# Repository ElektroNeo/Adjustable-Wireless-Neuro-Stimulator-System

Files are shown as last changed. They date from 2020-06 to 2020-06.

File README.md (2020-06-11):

# Adjustable Wireless Neuro Stimulator System
This project is made for the Design Project lecture. With this system, you can control output current by using Android application which made with [App Inventor](http://ai2.appinventor.mit.edu/).
### Notes
- The maximum output current is 5.5mA.
- The maximum Pulse High, Pulse Low, and Working Time values on the application are 255.
- Current source and system power supplies must not share the same ground.

## Used Microcontroller Features
In the software used PIC16F1713 microcontroller features listed below.
- DAC
- EUSART
- Timer0
- Interrupt

## Components
- 1x PIC16F1713 Microcontroller
- 1x HC-06 Bluethoot Module
- 2x LMC6482IN Amplifier
- 1x L7805 5V Regulator
- 3x Screw Terminal
- +12V DC Power Supply (for the current source)
- +7V - +12V DC Power Supply or Battery (for the system)
- 2x 120 Ohm Resistor
- 2x 560 Ohm Resistor
- 3x 1k Ohm Resistor
- 2x 330 Ohm Resistor
- 2x 10uF Capacitor
- 2x Red LED
- 1x Green LED
- Others (Button, pin header, switch)

## App
| Disconnected App  | Connected App |
| :---: | :---: |
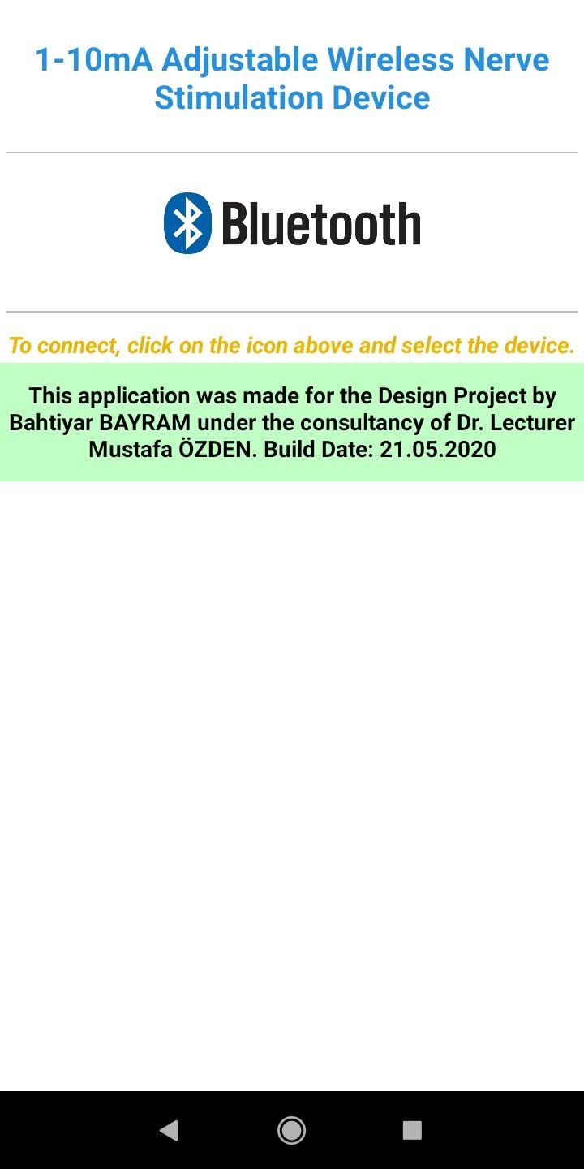
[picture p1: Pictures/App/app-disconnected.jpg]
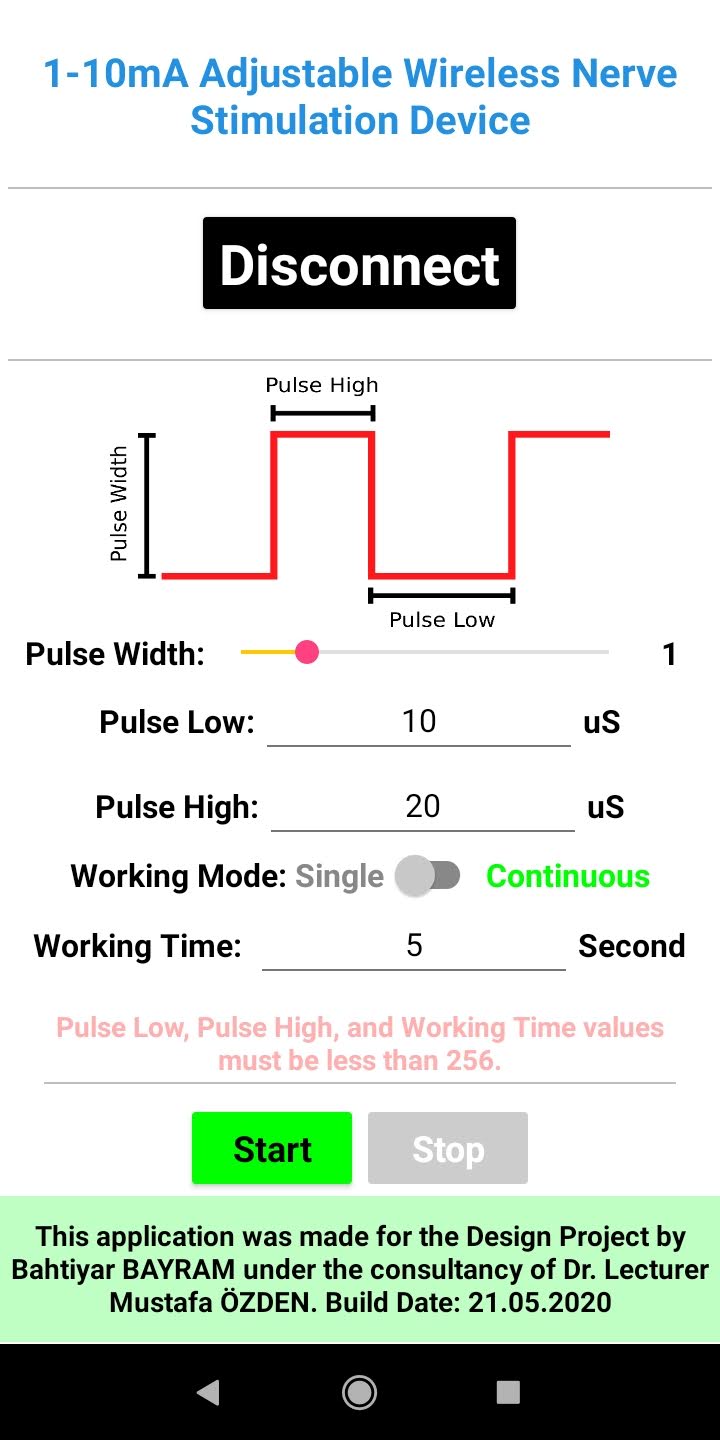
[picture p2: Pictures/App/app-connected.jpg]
|   |   |

## Schematic
| |  |
| :---: | :---: |
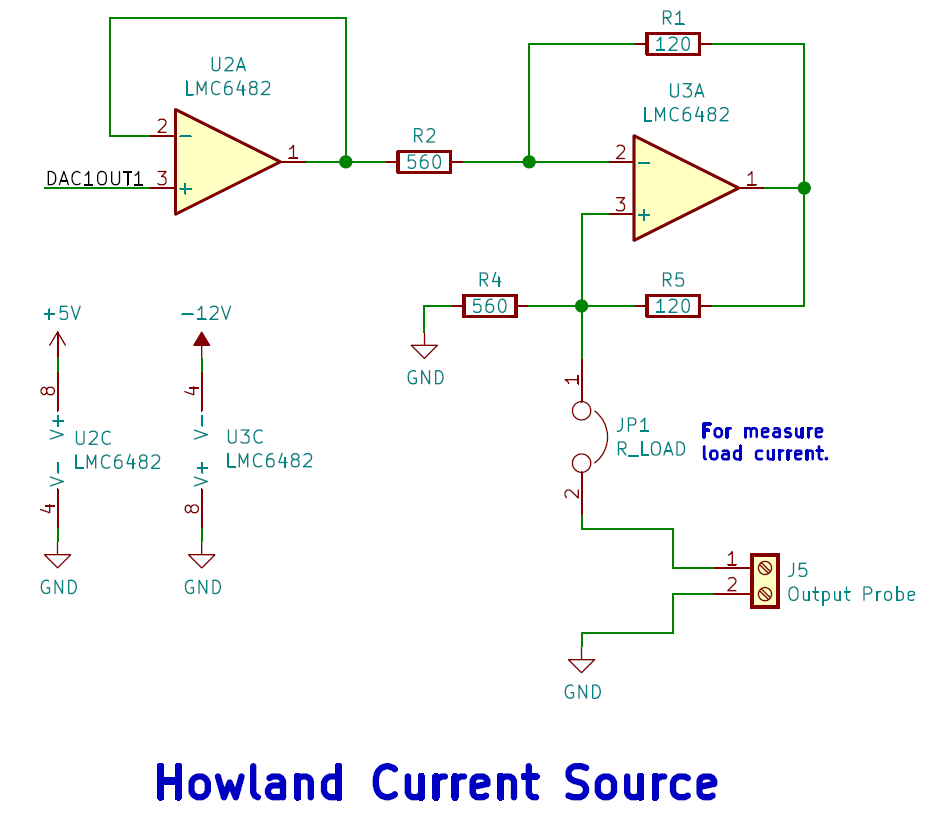
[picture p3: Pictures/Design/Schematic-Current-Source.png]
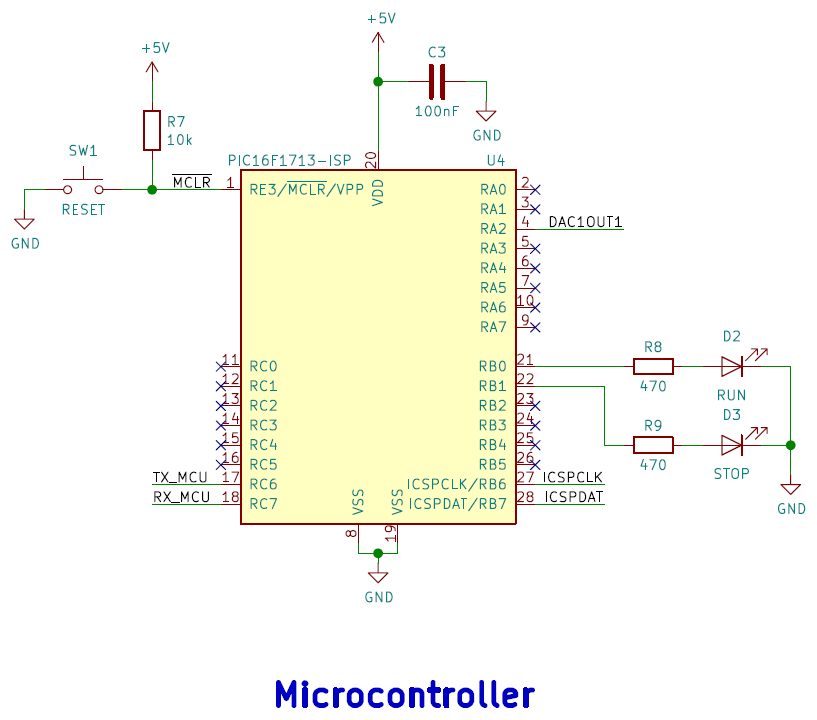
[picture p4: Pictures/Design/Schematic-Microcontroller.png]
|   |   |
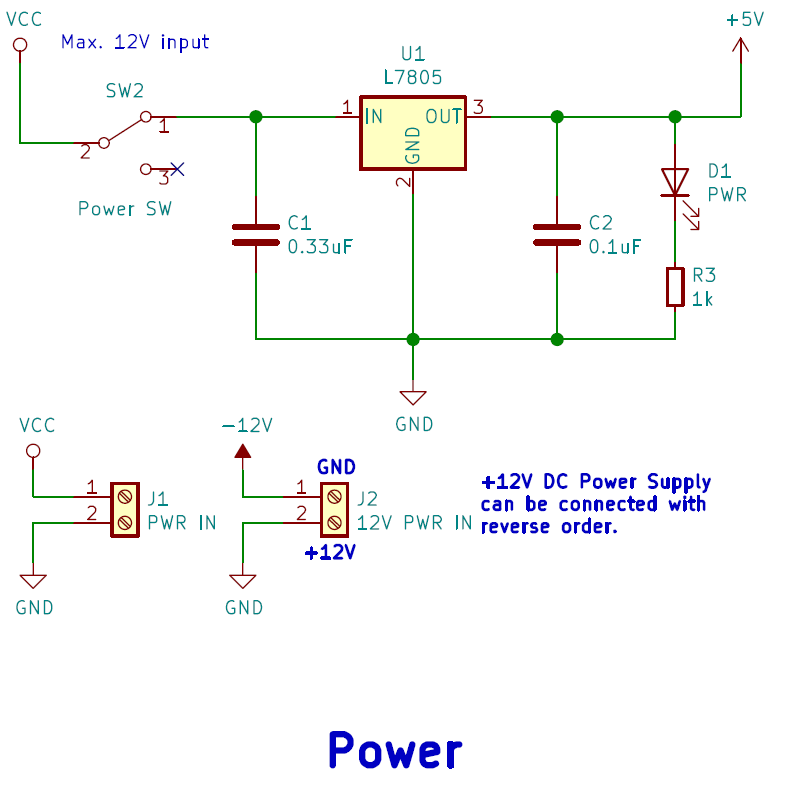
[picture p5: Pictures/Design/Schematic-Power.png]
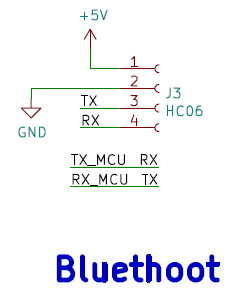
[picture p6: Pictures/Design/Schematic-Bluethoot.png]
|   |   |
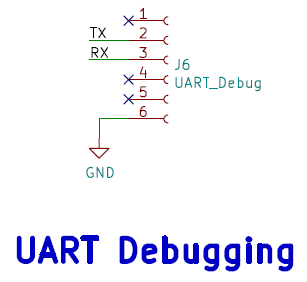
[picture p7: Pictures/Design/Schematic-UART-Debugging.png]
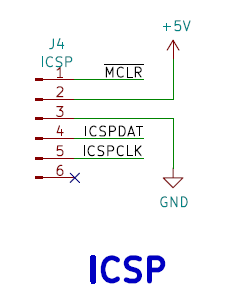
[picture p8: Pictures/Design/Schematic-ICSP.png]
|   |   |

## 3D Design
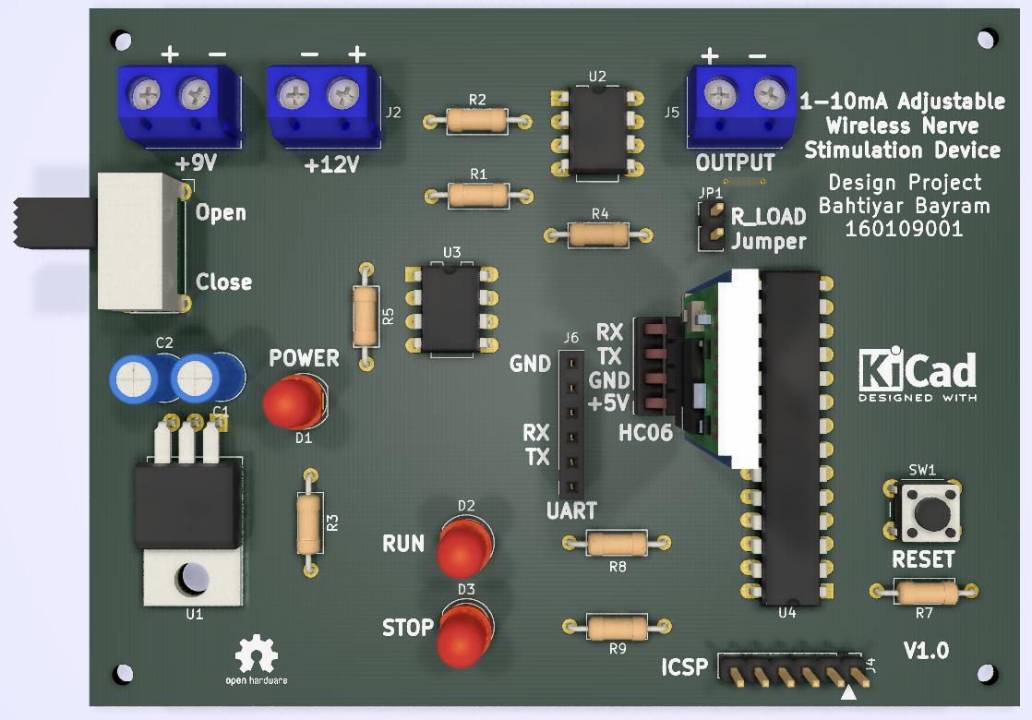
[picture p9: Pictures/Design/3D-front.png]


## Product
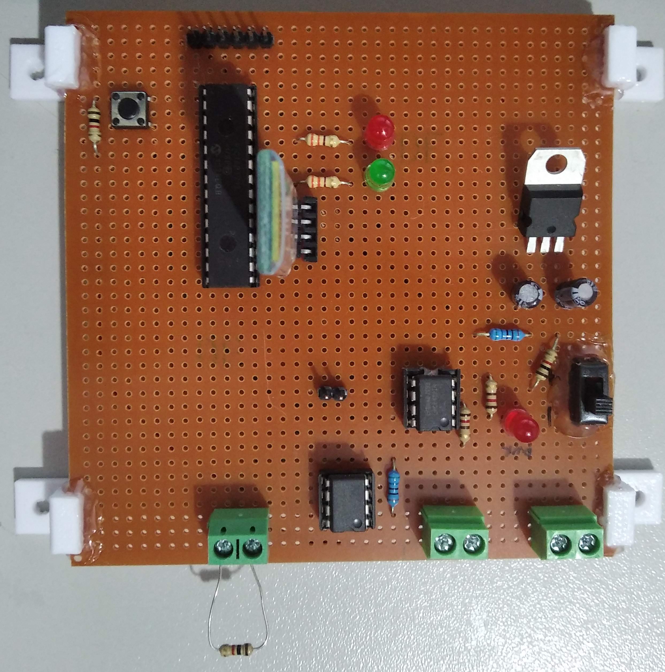
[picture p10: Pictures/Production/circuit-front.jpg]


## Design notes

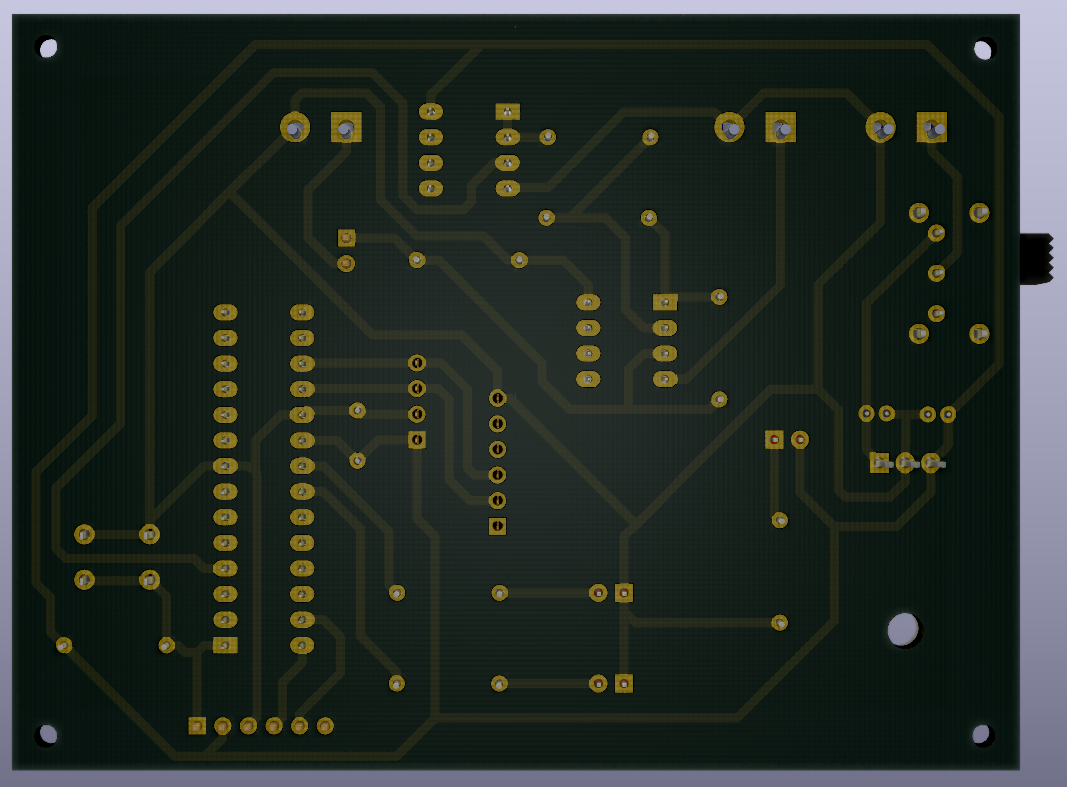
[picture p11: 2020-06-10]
Pictures/Design/3D-back.png

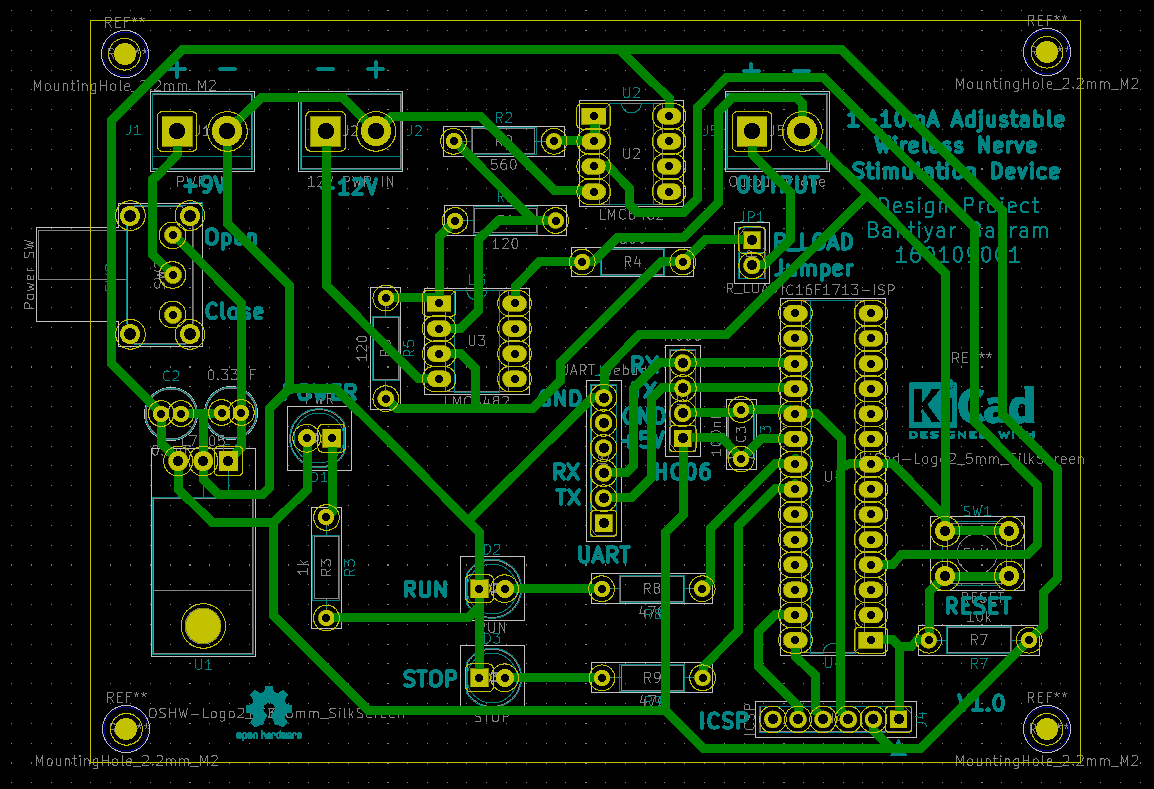
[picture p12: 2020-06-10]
Pictures/Design/PCB.png

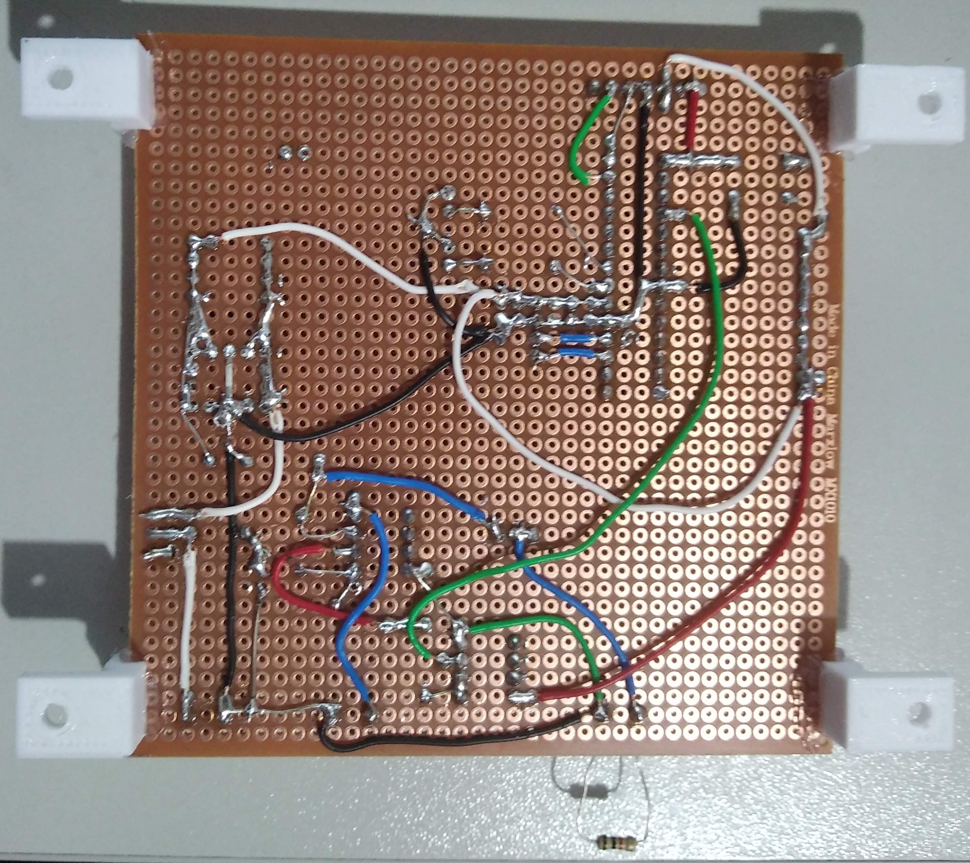
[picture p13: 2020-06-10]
Pictures/Production/circuit-back.jpg

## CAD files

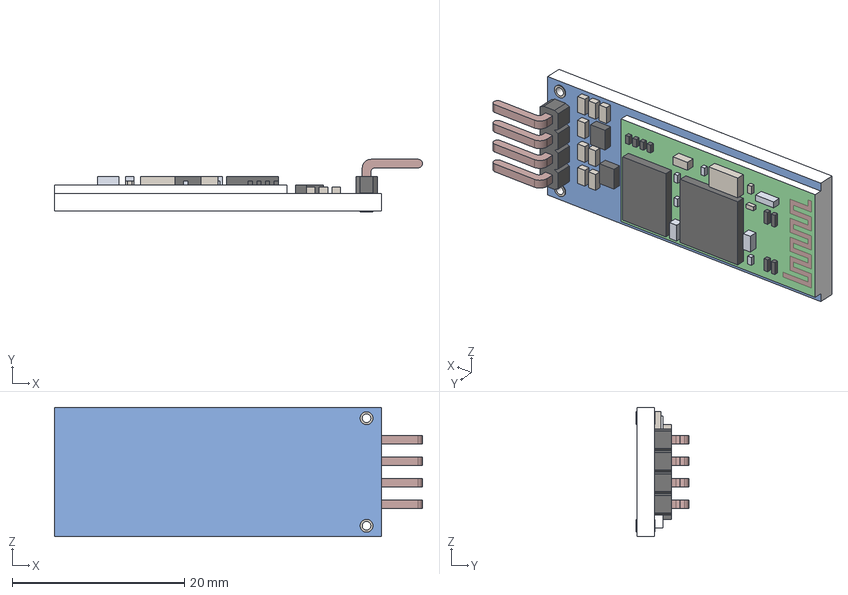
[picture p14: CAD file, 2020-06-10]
Hardware/adjustable-wireless-neuro-stimulator-system/3D-Parts/HC-06.stp
42.8 x 6.10 x 15.0 mm

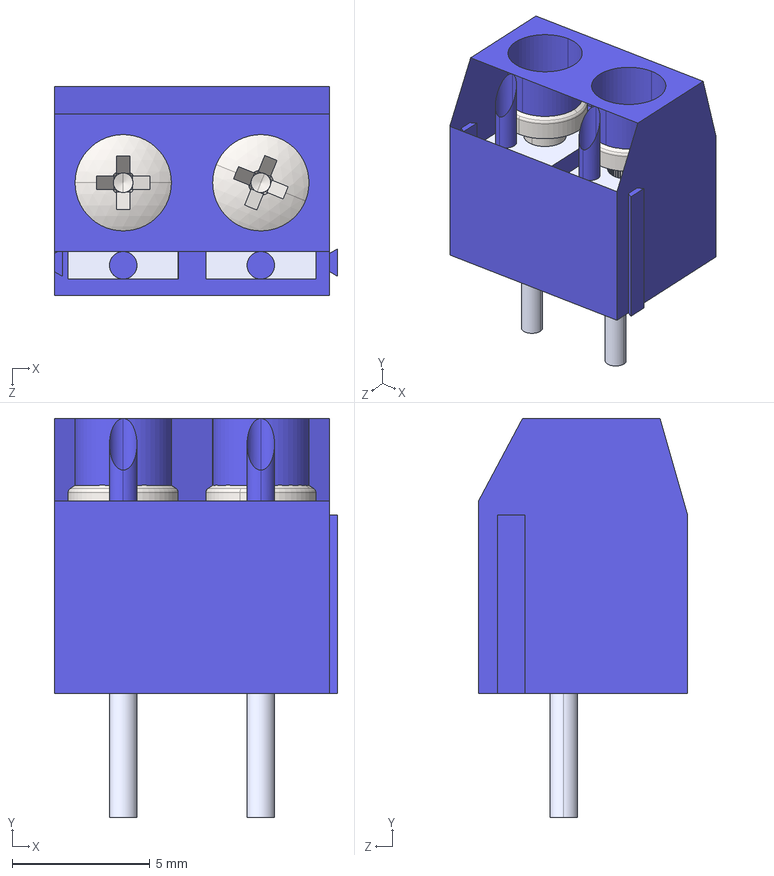
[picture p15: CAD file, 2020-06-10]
Hardware/adjustable-wireless-neuro-stimulator-system/3D-Parts/ScrewTerminal.STEP
10.3 x 14.5 x 7.60 mm
ScrewTerminalCover
Pin x 2
pan head cross recess screw_iso_ISO 7045 - M2 x 3 - Z - 3N x 2

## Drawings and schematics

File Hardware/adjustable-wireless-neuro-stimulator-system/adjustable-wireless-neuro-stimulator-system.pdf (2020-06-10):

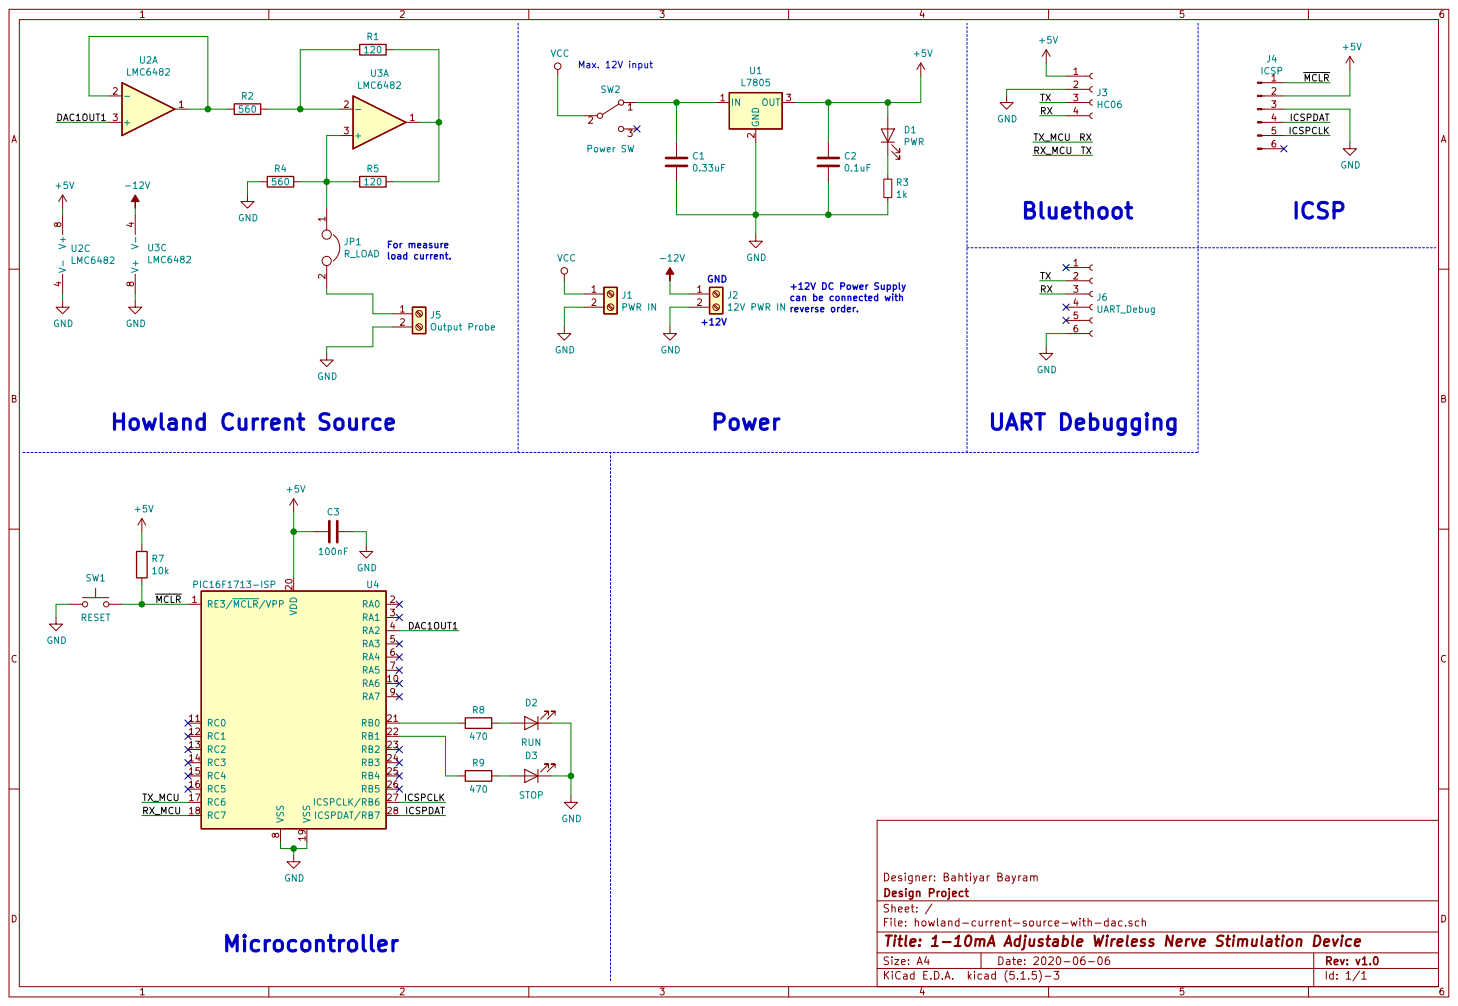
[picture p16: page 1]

Designer: Bahtiyar Bayram
File: howland-current-source-with-dac.sch Sheet: / Design Project

Id: 1/1 Title: 1-10mA Adjustable Wireless Nerve Stimulation Device

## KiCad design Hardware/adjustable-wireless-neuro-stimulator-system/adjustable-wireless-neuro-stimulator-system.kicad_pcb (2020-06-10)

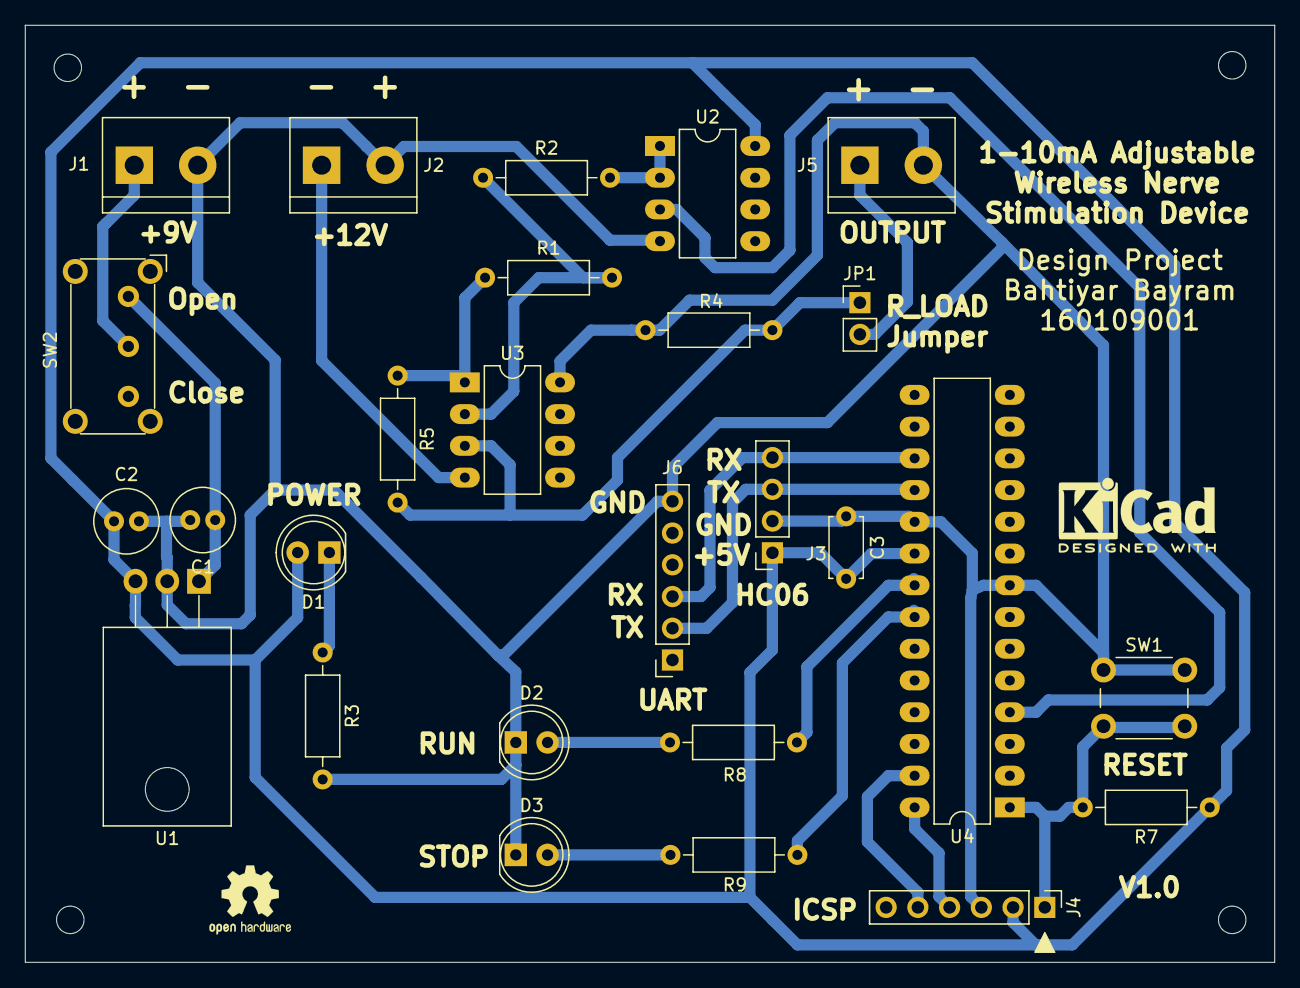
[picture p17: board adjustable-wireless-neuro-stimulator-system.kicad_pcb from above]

Board: 2 copper layers, 100.0 x 75.0 mm, 27 parts (0 on the bottom side), 21 nets.

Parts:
C1: 0.33uF; C_Radial_D5.0mm_H11.0mm_P2.00mm
C2: 0.1uF; C_Radial_D5.0mm_H11.0mm_P2.00mm
C3: 100nF; C_Disc_D4.7mm_W2.5mm_P5.00mm
D1: PWR; LED_D5.0mm
D2: RUN; LED_D5.0mm
D3: STOP; LED_D5.0mm
J1: PWR IN; TerminalBlock_bornier-2_P5.08mm
J2: 12V PWR IN; TerminalBlock_bornier-2_P5.08mm
J3: HC06; PinSocket_1x04_P2.54mm_Vertical
J4: ICSP; PinHeader_1x06_P2.54mm_Vertical
J5: Output Probe; TerminalBlock_bornier-2_P5.08mm
J6: UART_Debug; PinSocket_1x06_P2.54mm_Vertical
JP1: R_LOAD; PinHeader_1x02_P2.54mm_Vertical
R1, R5: 120; R_Axial_DIN0207_L6.3mm_D2.5mm_P10.16mm_Horizontal
R2, R4: 560; R_Axial_DIN0207_L6.3mm_D2.5mm_P10.16mm_Horizontal
R3: 1k; R_Axial_DIN0207_L6.3mm_D2.5mm_P10.16mm_Horizontal
R7: 10k; R_Axial_DIN0207_L6.3mm_D2.5mm_P10.16mm_Horizontal
R8, R9: 470; R_Axial_DIN0207_L6.3mm_D2.5mm_P10.16mm_Horizontal
SW1: RESET; SW_PUSH_6mm_H5mm
SW2: Power SW; SW_E-Switch_EG1224_SPDT_Angled
U1: L7805; TO-220-3_Horizontal_TabDown
U2, U3: LMC6482; DIP-8_W7.62mm_LongPads
U4: PIC16F1713-ISP; DIP-28_W7.62mm_LongPads

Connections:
+5V: C2.1, C3.2, D1.2, J3.1, J4.2, R7.1, U1.3, U2.8, U4.20
-12V: J2.1, U3.4
/DAC1OUT1: U2.3, U4.4
/ICSPCLK: J4.5, U4.27
/ICSPDAT: J4.4, U4.28
/RX: J3.4, J6.3, U4.17
/RX_MCU: J3.3, J6.2, U4.18
/~MCLR: J4.1, R7.2, SW1.2, U4.1
GND: C1.2, C2.2, C3.1, D2.1, D3.1, J1.2, J2.2, J3.2, J4.3, J5.2, J6.6, R3.2, R4.2, SW1.1, U1.2, U2.4, U3.8, U4.8, U4.19
unnamed: C1.1, SW2.1, U1.1
unnamed: D1.1, R3.1
unnamed: D2.2, R8.1
unnamed: D3.2, R9.1
unnamed: J5.1, JP1.2
unnamed: JP1.1, R4.1, R5.2, U3.3
unnamed: R1.1, R5.1, U3.1
unnamed: R1.2, R2.1, U3.2
unnamed: R2.2, U2.1, U2.2
unnamed: R8.2, U4.21
unnamed: R9.2, U4.22
VCC: J1.1, SW2.2

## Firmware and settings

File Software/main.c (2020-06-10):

/*
 * File:   main.c
 * Author: Bahtiyar Bayram
 *
 * Created on March 8, 2020, 8:50 AM
 */


#include "config.h"

#define IN_MODE -2
#define NO_MODE -1
#define W_MODE  1
#define L_MODE  2
#define H_MODE  3
#define T_MODE  4
#define S_MODE  5

#define CONTINUOUS  0
#define SINGLE      1

#define STOP        0
#define RUN         1
#define WAIT        2
#define CALCULATE   3

int8_t mode = NO_MODE;
float mV;
uint8_t pulseWidth, pulseLow, pulseHigh, workingTime;
uint16_t timeCounter = 0;
uint8_t data = 0, state = STOP, workingMode = CONTINUOUS;

// Interrupt Service Routine
void __interrupt() ISR(void) {
    // Timer0 Interrupt - Freq = 100.16 Hz - Period = 0.009984 seconds
    if (INTCONbits.TMR0IF) {
        timeCounter++;
        if(timeCounter >= 100*workingTime) {
            state = STOP;
            timeCounter = 0;
            // Disable Timer 0 Interrupt
            INTCONbits.TMR0IE = 0;
        }
        INTCONbits.TMR0IF = 0;    // Clear the flag
        TMR0 = 100;           // Reset the timer preset count
    }
    
    // If Receive UART interrupt appears
    if(PIR1bits.RCIF) {
        data = EUSART_ReadByte();
        // If data is $ then set to IN_MODE
        if(data == '$' && mode == NO_MODE) {
            mode = IN_MODE;
        }
        // If data is in mode
        else if (mode == IN_MODE) {
            // Data is in Signal Width Mode (current)
            if(data == 'W') {
                mode = W_MODE;
            } 
            // Data is in Signal Low Time Mode
            else if (data == 'L') {
                mode = L_MODE;
            } 
            // Data is in Signal High Time Mode
            else if (data == 'H') {
                mode = H_MODE;
            } 
            // Signal is continuous
            else if (data == 'C') {
                workingMode = CONTINUOUS;
                state = CALCULATE;
                mode = NO_MODE;
            } 
            // Signal is single
            else if (data == 'T') {
                mode = T_MODE;
                workingMode = SINGLE;
            } 
            // Stop command appears
            else if (data == 'S') {
                // Run stop command...
                state = STOP;
                mode = NO_MODE;
            }
        } 
        // Get Signal Width data
        else if (mode == W_MODE) {
            pulseWidth = data;
            mode = NO_MODE;
        } 
        // Get Signal Low Time data
        else if (mode == L_MODE) {
            pulseLow = data;
            mode = NO_MODE;
        } 
        // Get Signal High Time data
        else if (mode == H_MODE) {
            pulseHigh = data;
            mode = NO_MODE;
        } 
        // Get Working Time data
        else if (mode == T_MODE) {
            workingTime = data;
            state = CALCULATE;
            mode = NO_MODE;
        }
    }   
}

// Delay us function
void delay_us(uint16_t time) {
    for(uint16_t i = 0; i < time; ++i) {
        __delay_us(1);
    }
}

void main(void) {
    // Oscillator Initialize
    OSCCONbits.IRCF = 0b1111;   // 16 MHz
    OSCCONbits.SCS = 0b10;      // Internal oscillator
    // Wait until HFINTOSC is ready
    while(!OSCSTATbits.HFIOFR);
    
    // Disable analog pins
    ANSELA = 0;
    ANSELB = 0;
    ANSELC = 0;
    
    // Initialize DAC
    DAC1_Init();
    // Set output voltage in mV
    DAC1_Out(0);
    // Initialize UART
    EUSART_Init();
    
    // Timer0 Initialize
    //Timer0 Period = 0.009984 seconds
    // TMR0 Clock Source Select to Internal Clock (CLKO)
    OPTION_REGbits.T0CS = 0;
    // TMR0 Source Edge Select bit 0 = low/high
    OPTION_REGbits.T0SE = 0;
    // Prescaler is assigned to the Timer0
    OPTION_REGbits.PSA = 0;
    // Set Prescaler to 1:256
    OPTION_REGbits.PS2 = 1;
    OPTION_REGbits.PS1 = 1;
    OPTION_REGbits.PS0 = 1;
    // Set timer register
    TMR0 = 100;
    
    // Enable UART Receive Interrupt
    PIE1bits.RCIE = 1;
    // Disable Timer 0 Interrupt
    INTCONbits.TMR0IE = 0;
    // Clear Timer 0 interrupt flag
    INTCONbits.TMR0IF = 0;
    // Enable Peripheral Interrupts
    INTCONbits.PEIE = 1;
    // Enable Global Interrupt
    INTCONbits.GIE = 1;
    
    // Set IOs
    TRISBbits.TRISB0 = 0;
    TRISBbits.TRISB1 = 0;
    PORTBbits.RB0 = 0;  // Run LED
    PORTBbits.RB1 = 0;  // Stop LED
    
    // 200ms delay
    __delay_ms(200);        
    
    // Infinite loop
    while(1) {
        // If stop command appears then set output voltage to 0
        if (state == STOP) {
            DAC1_Out(0);
            PORTBbits.RB0 = 0;  // Run LED
            PORTBbits.RB1 = 1;  // Stop LED
            timeCounter = 0;
            // Disable Timer 0 Interrupt
            INTCONbits.TMR0IE = 0;
            INTCONbits.TMR0IF = 0;    // Clear the flag
            TMR0 = 100;           // Reset the timer preset count
            state = WAIT;
        }
        // If new data appears then calculate output voltage
        else if(state == CALCULATE) {
            // Calculate output voltage in mV
            mV = 56.2*pulseWidth - 25.9;
            state = RUN;
        }
        // If output voltage calculated then run commands
        else if (state == RUN) {
            PORTBbits.RB0 = 1;  // Run LED
            PORTBbits.RB1 = 0;  // Stop LED
            
            // If workingMode is continuous then run commands infinitely
            if(workingMode == CONTINUOUS) {
                while(state == RUN) {
                    if(pulseLow == 0) {
                        DAC1_Out(mV);
                        delay_us(pulseHigh);
                    }
                    else {
                        DAC1_Out(mV);
                        delay_us(pulseHigh);
                        DAC1_Out(0);
                        delay_us(pulseLow);
                    }
                }
            }
            // If workingMode is single then run commands for a given time
            else if(workingMode == SINGLE) {
                // Enable Timer 0 Interrupt
                INTCONbits.TMR0IE = 1;
                // Run commands for a given time
                while(state == RUN) {
                    if(pulseLow == 0) {
                        DAC1_Out(mV);
                        delay_us(pulseHigh);
                    }
                    else {
                        DAC1_Out(mV);
                        delay_us(pulseHigh);
                        DAC1_Out(0);
                        delay_us(pulseLow);
                    }
                }
                state = STOP;
            }
        }
    }
}
